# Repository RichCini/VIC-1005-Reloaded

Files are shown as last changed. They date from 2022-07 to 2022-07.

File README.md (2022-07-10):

# VIC-1005-Reloaded
The VIC-1005R is a 3-slot expansion backplane for the VIC-20 computer system.

The VIC-1005R (Reloaded) is a reimagination of the original but customized
for the various "reloaded" VIC-20s that have a vertical (Atari 2600-like)
expansion connector. It uses two boards -- the expansion connector board
and the multi-slot backplane -- connected by a 2x25 IDC ribbon cable.
It includes a reset switch and separate fuse to protect the backplane.

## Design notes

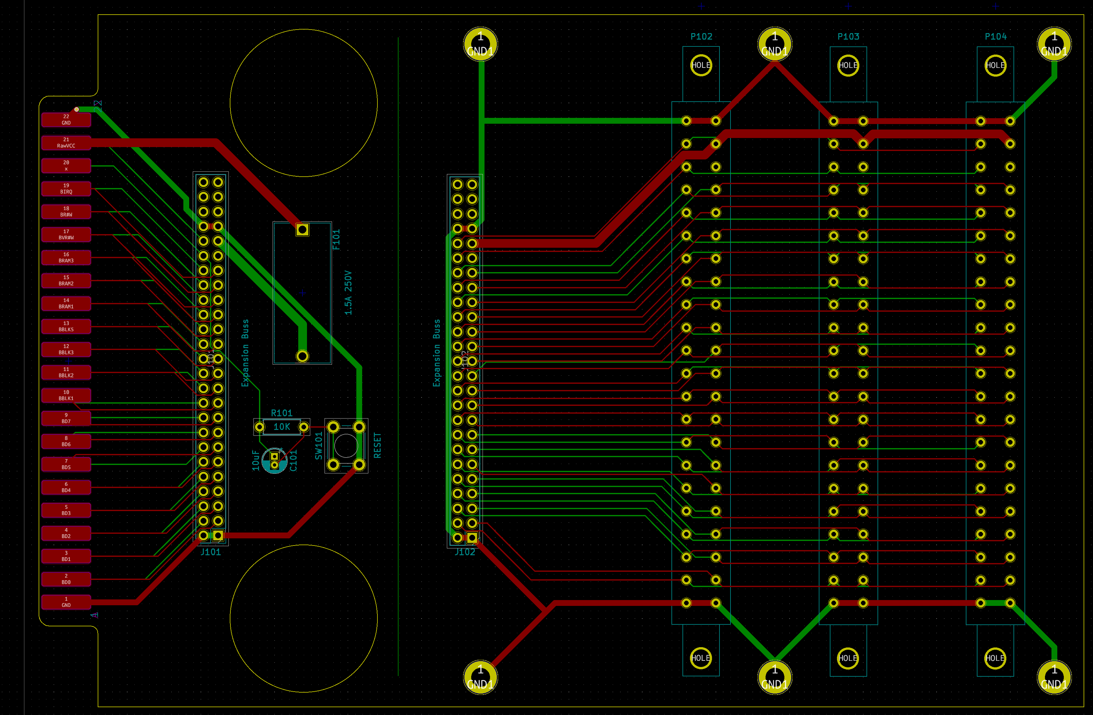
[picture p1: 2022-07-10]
Screen Shot 2022-07-10 at 12.23.37 PM.png

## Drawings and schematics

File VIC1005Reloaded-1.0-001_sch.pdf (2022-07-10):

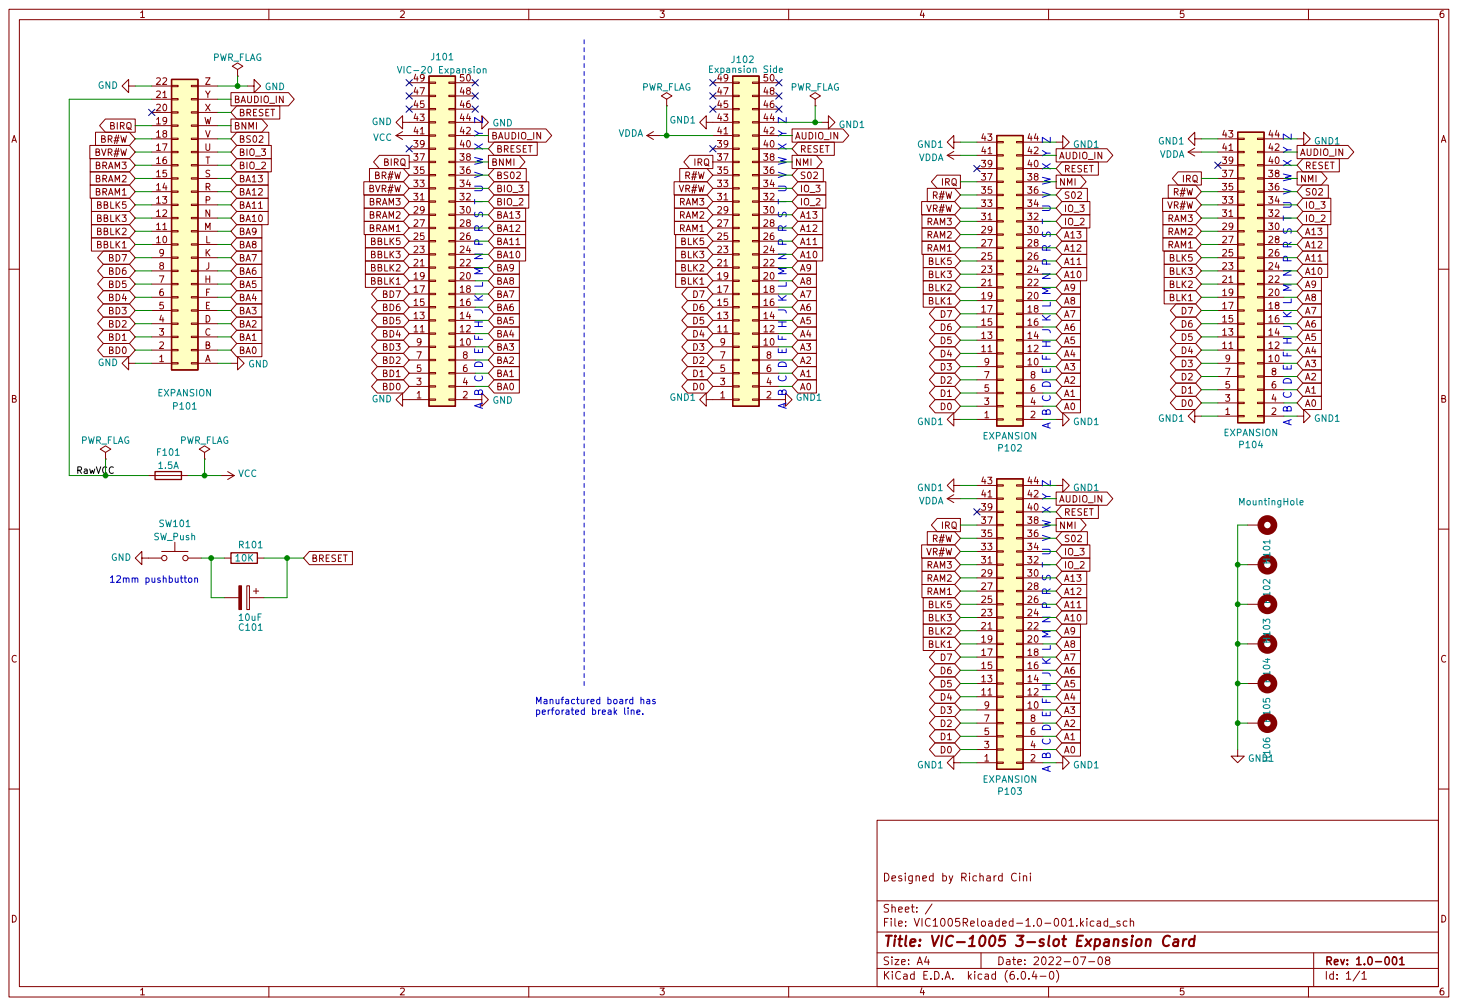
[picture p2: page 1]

Id: 1/1 Title: VIC-1005 3-slot Expansion Card

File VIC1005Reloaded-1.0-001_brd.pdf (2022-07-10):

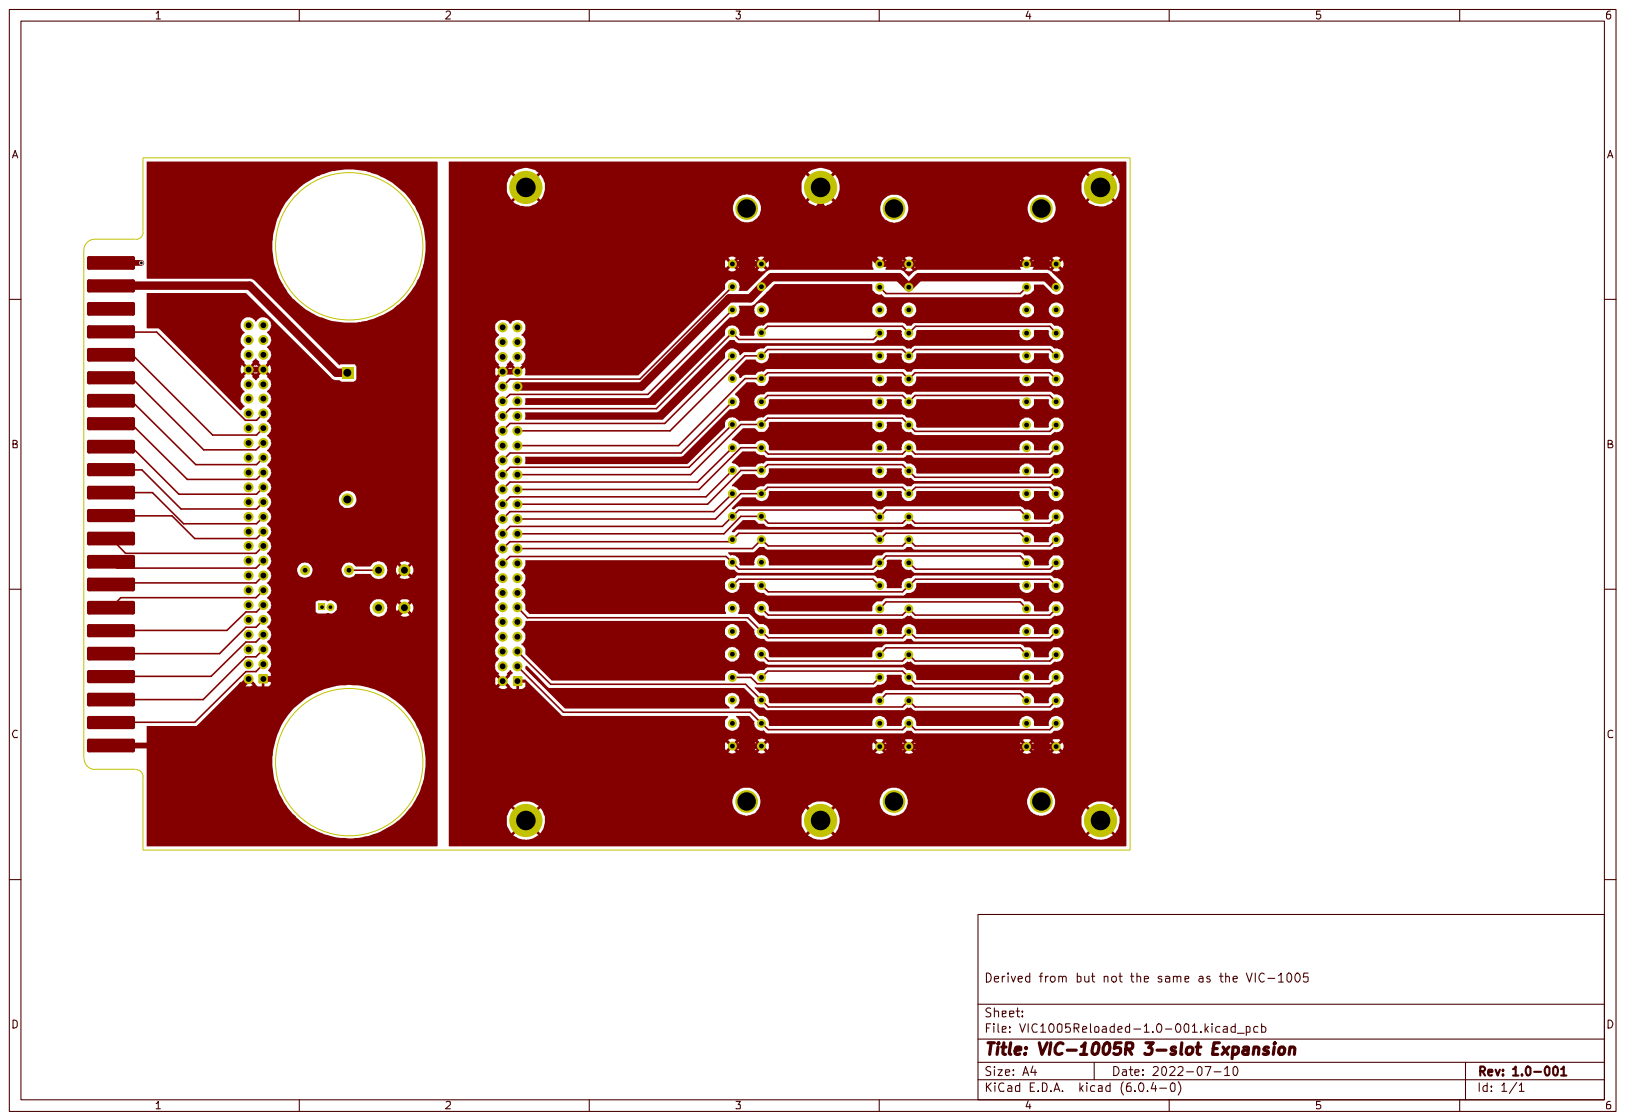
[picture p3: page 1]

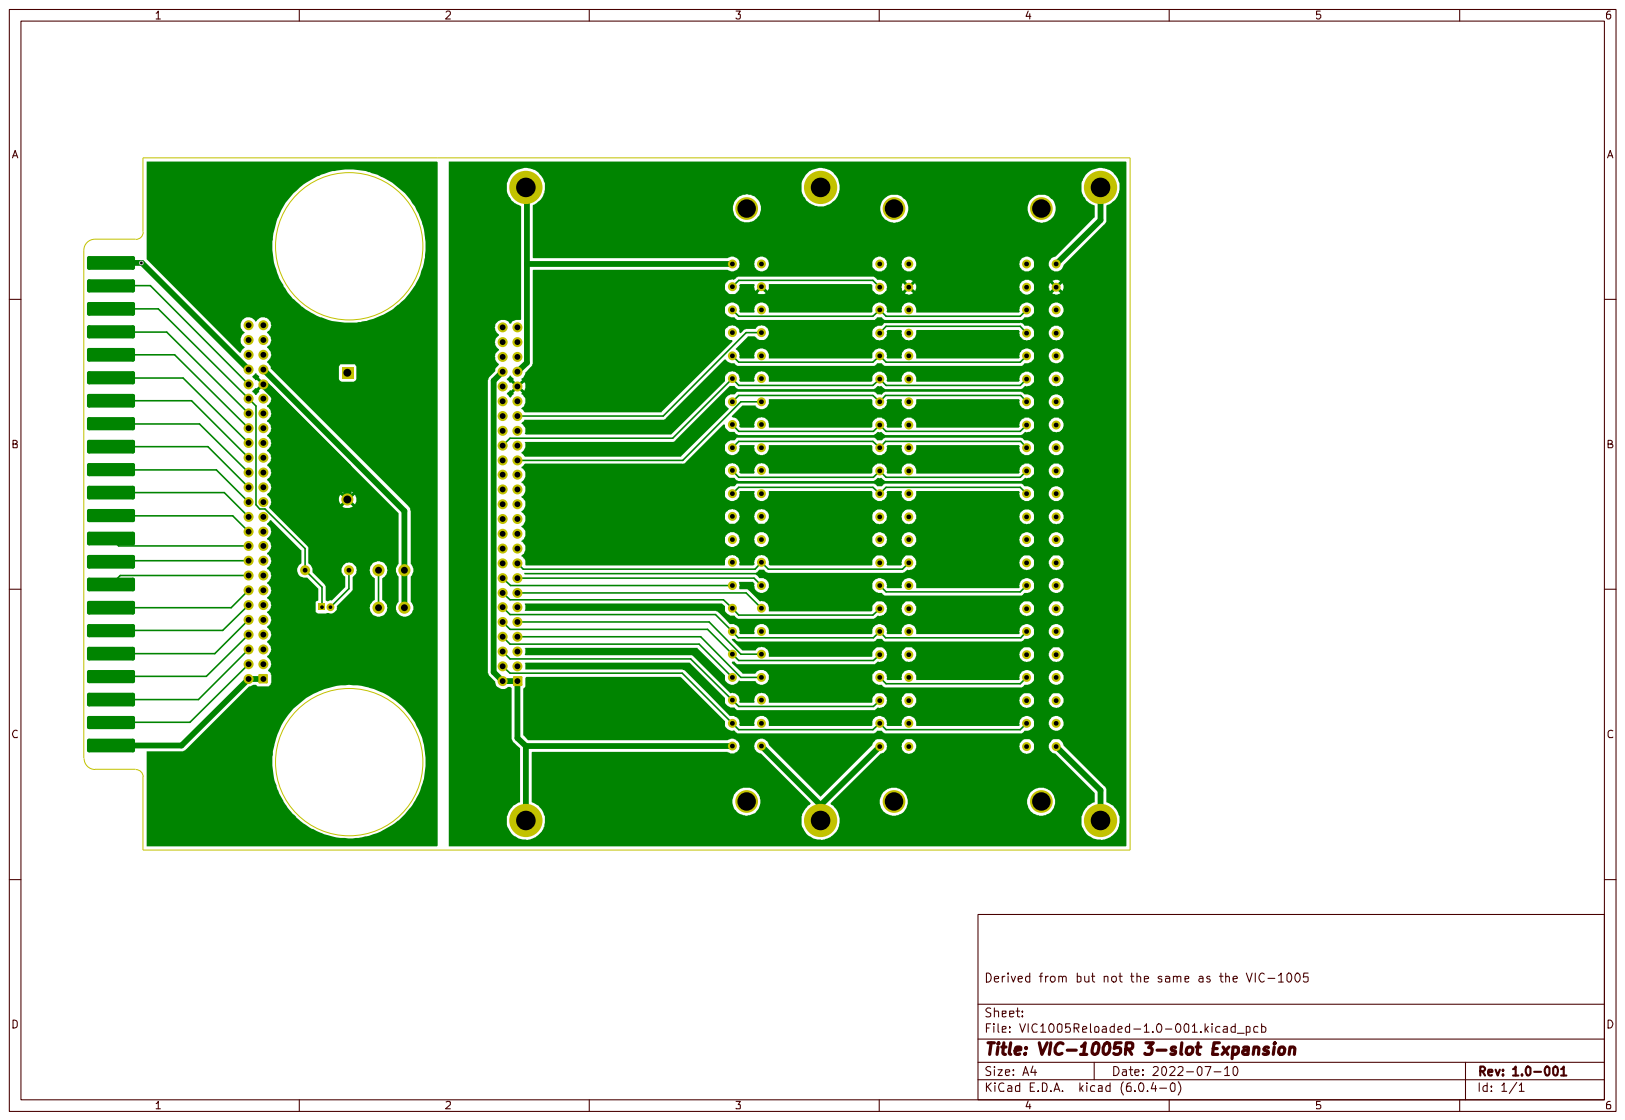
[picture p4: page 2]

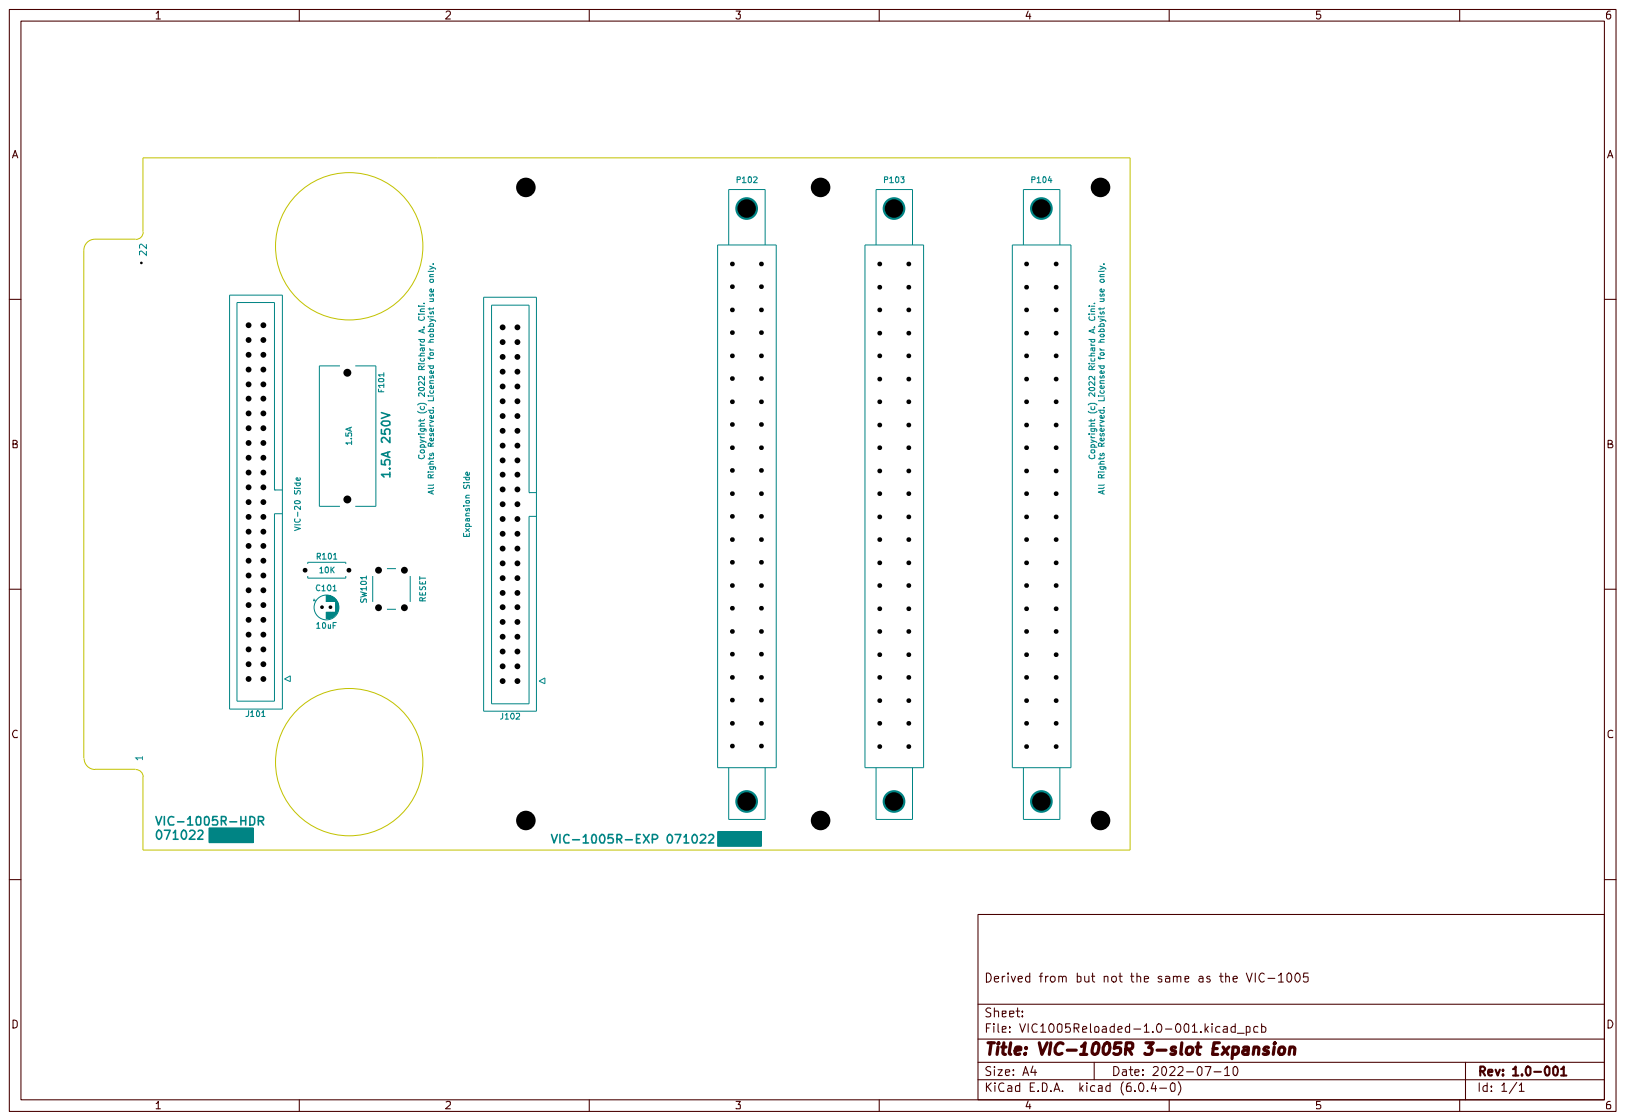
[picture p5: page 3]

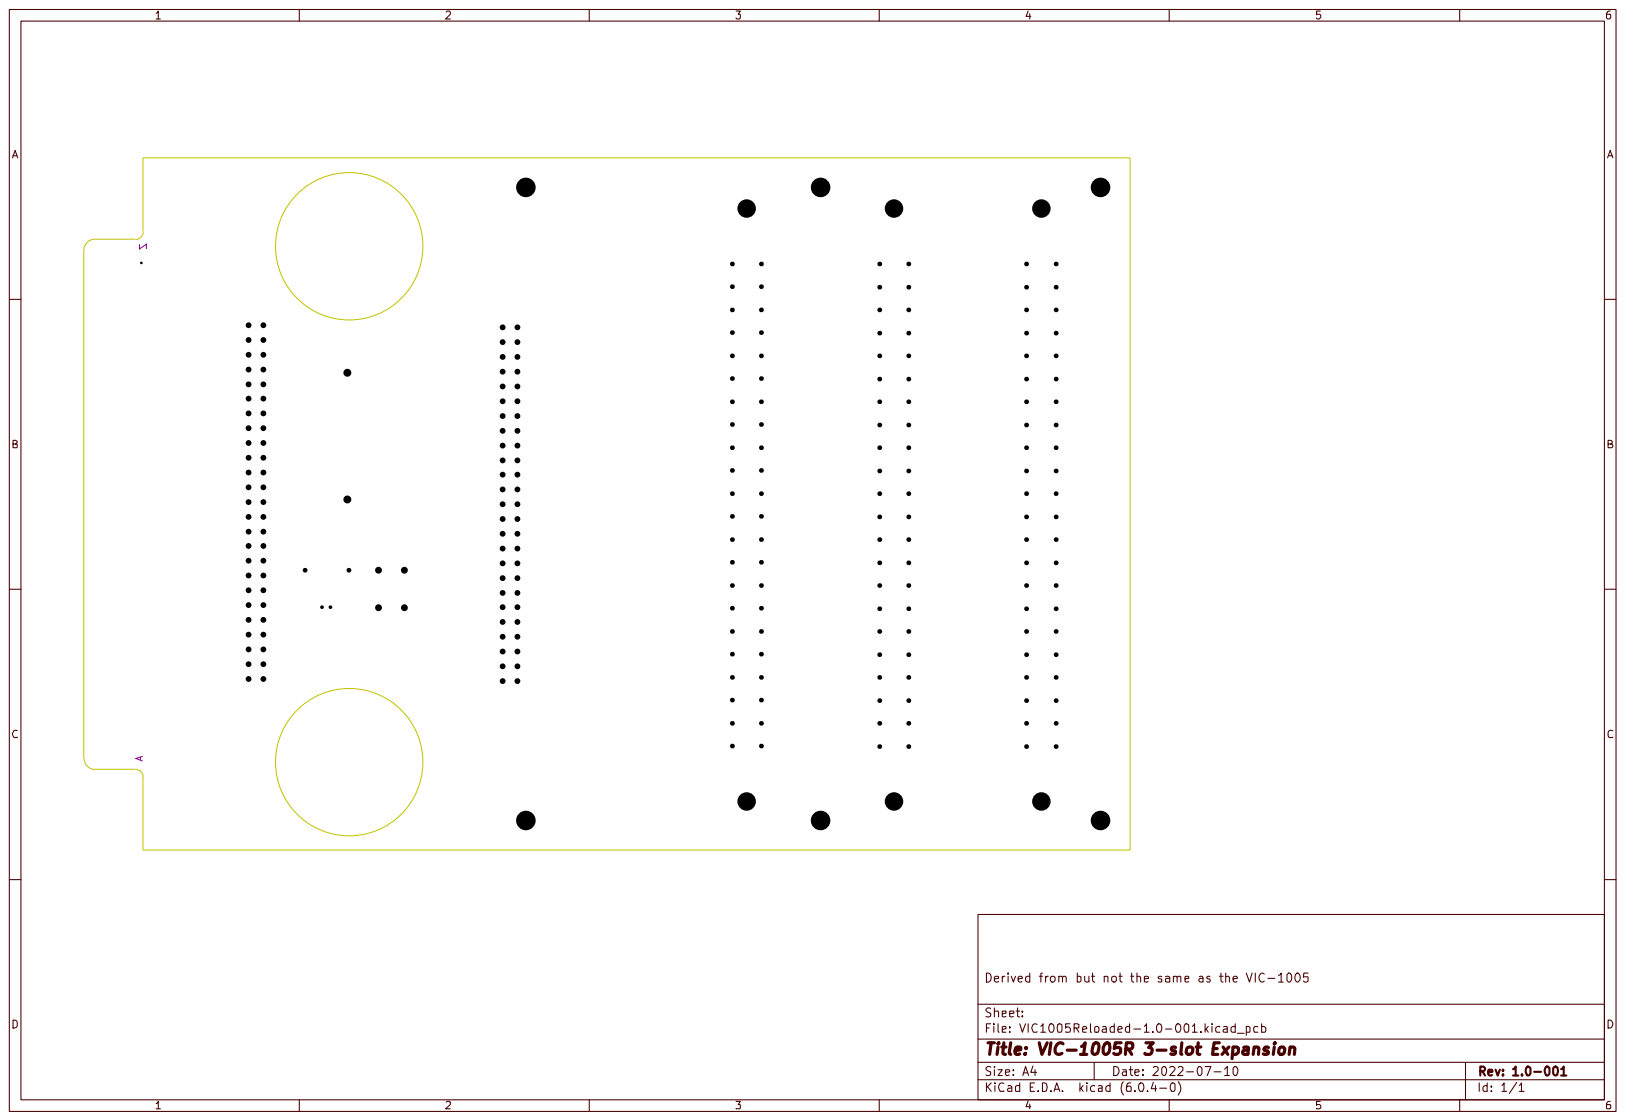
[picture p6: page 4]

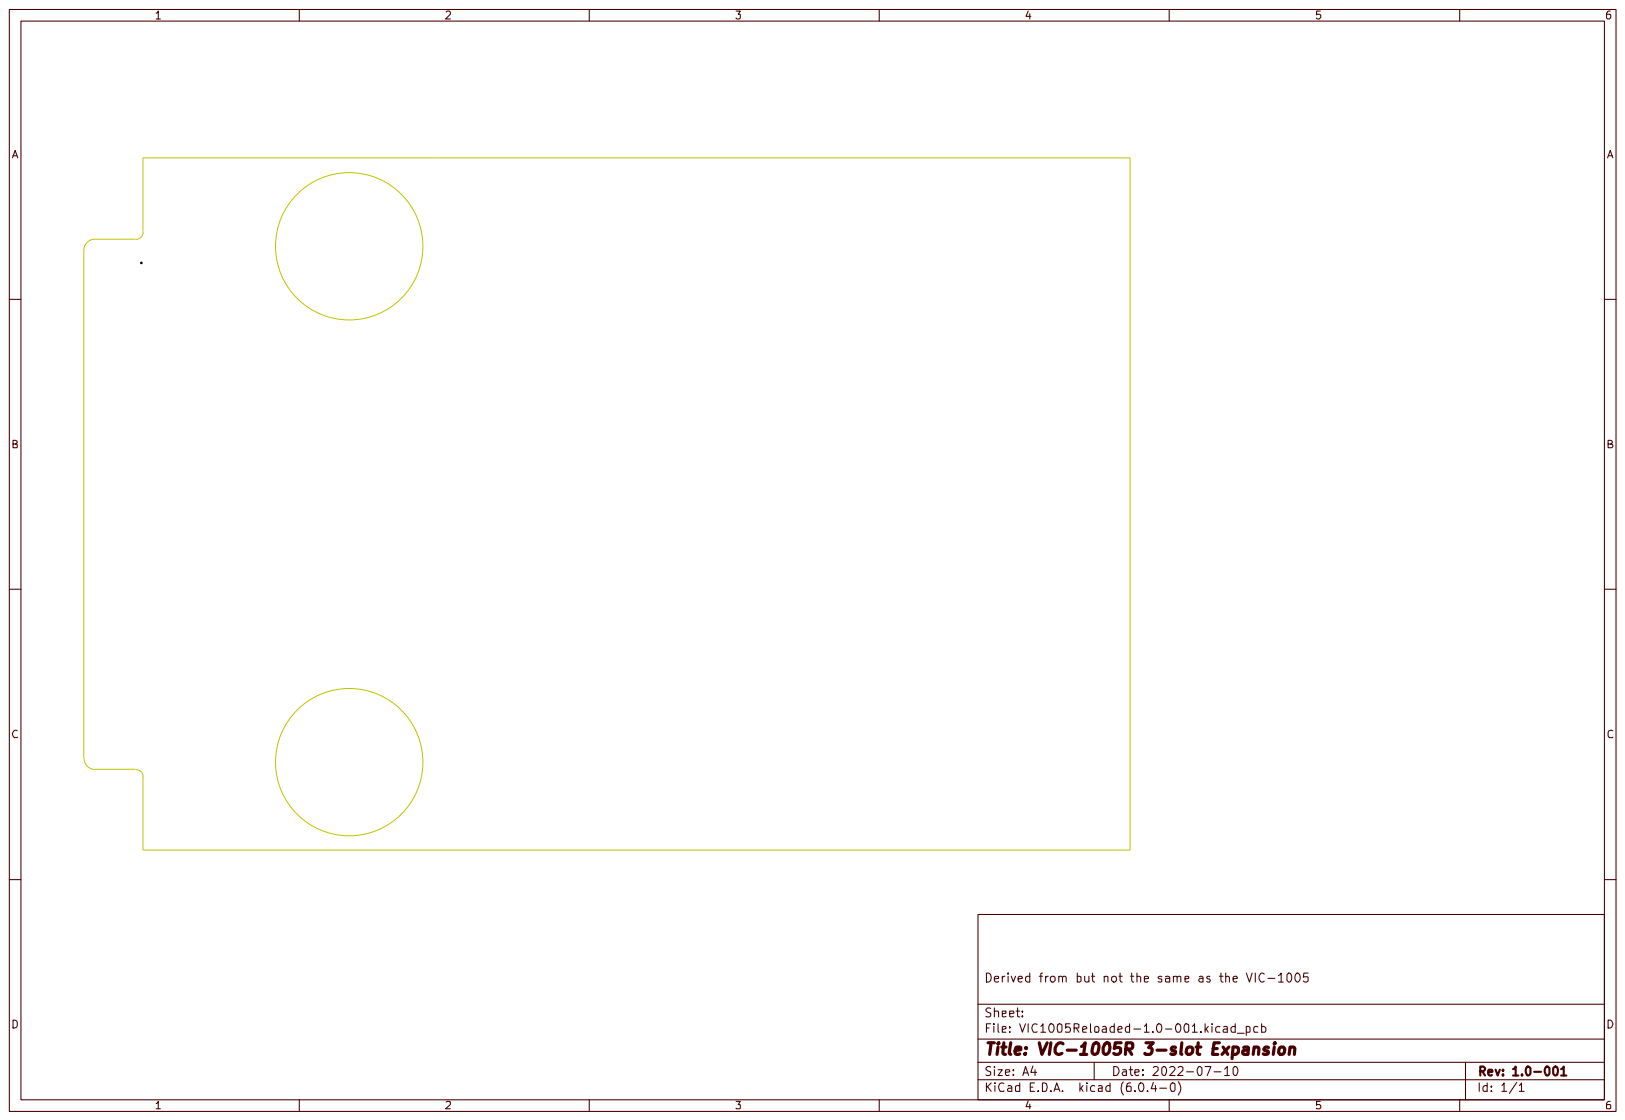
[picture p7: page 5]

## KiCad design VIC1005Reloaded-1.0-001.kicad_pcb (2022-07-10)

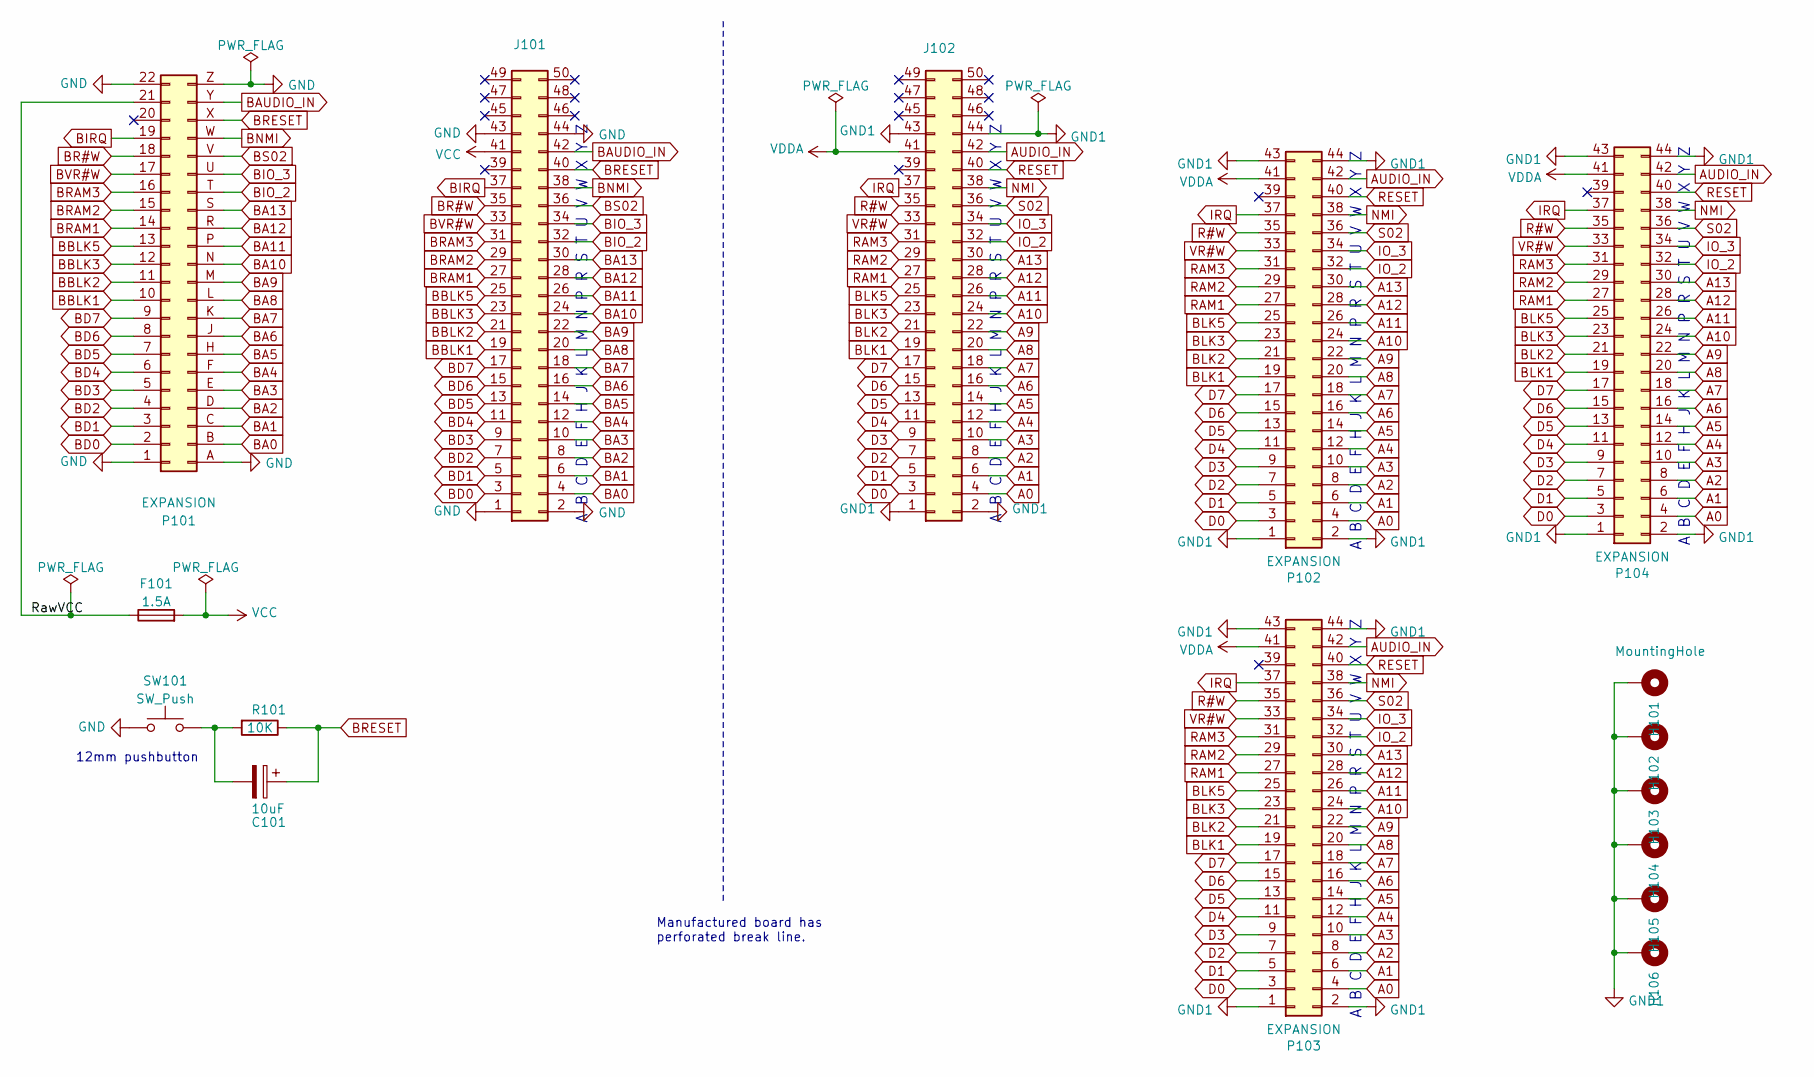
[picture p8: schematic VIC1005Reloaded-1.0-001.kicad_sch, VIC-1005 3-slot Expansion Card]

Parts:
C101: 10uF; CP_Radial_D4.0mm_P1.50mm
F101: 1.5A; FUSE_4527
H101, H102, H103, H104, H105, H106: MountingHole; MountingHole_3.2mm_M3_DIN965_Pad
J101, J102: (no value)
P101: EXPANSION; MA156-22-2
P102, P103, P104: EXPANSION; EDAC_02_22_Card_Edge_Connector
R101: 10K; R_Axial_DIN0207_L6.3mm_D2.5mm_P7.62mm_Horizontal
SW101: SW_Push; SW_PUSH_6mm

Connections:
/RawVCC: F101.1, P101.21
A0: J102.4, P102.4, P103.4, P104.4
A1: J102.6, P102.6, P103.6, P104.6
A2: J102.8, P102.8, P103.8, P104.8
A3: J102.10, P102.10, P103.10, P104.10
A4: J102.12, P102.12, P103.12, P104.12
A5: J102.14, P102.14, P103.14, P104.14
A6: J102.16, P102.16, P103.16, P104.16
A7: J102.18, P102.18, P103.18, P104.18
A8: J102.20, P102.20, P103.20, P104.20
A9: J102.22, P102.22, P103.22, P104.22
A10: J102.24, P102.24, P103.24, P104.24
A11: J102.26, P102.26, P103.26, P104.26
A12: J102.28, P102.28, P103.28, P104.28
A13: J102.30, P102.30, P103.30, P104.30
AUDIO_IN: J102.42, P102.42, P103.42, P104.42
BA0: J101.4, P101.B
BA1: J101.6, P101.C
BA2: J101.8, P101.D
BA3: J101.10, P101.E
BA4: J101.12, P101.F
BA5: J101.14, P101.H
BA6: J101.16, P101.J
BA7: J101.18, P101.K
BA8: J101.20, P101.L
BA9: J101.22, P101.M
BA10: J101.24, P101.N
BA11: J101.26, P101.P
BA12: J101.28, P101.R
BA13: J101.30, P101.S
BAUDIO_IN: J101.42, P101.Y
BBLK1: J101.19, P101.10
BBLK2: J101.21, P101.11
BBLK3: J101.23, P101.12
BBLK5: J101.25, P101.13
BD0: J101.3, P101.2
BD1: J101.5, P101.3
BD2: J101.7, P101.4
BD3: J101.9, P101.5
BD4: J101.11, P101.6
BD5: J101.13, P101.7
BD6: J101.15, P101.8
BD7: J101.17, P101.9
BIO_2: J101.32, P101.T
BIO_3: J101.34, P101.U
BIRQ: J101.37, P101.19
BLK1: J102.19, P102.19, P103.19, P104.19
BLK2: J102.21, P102.21, P103.21, P104.21
BLK3: J102.23, P102.23, P103.23, P104.23
BLK5: J102.25, P102.25, P103.25, P104.25
BNMI: J101.38, P101.W
BR#W: J101.35, P101.18
BRAM1: J101.27, P101.14
BRAM2: J101.29, P101.15
BRAM3: J101.31, P101.16
BRESET: C101.1, J101.40, P101.X, R101.1
BS02: J101.36, P101.V
BVR#W: J101.33, P101.17
D0: J102.3, P102.3, P103.3, P104.3
D1: J102.5, P102.5, P103.5, P104.5
D2: J102.7, P102.7, P103.7, P104.7
D3: J102.9, P102.9, P103.9, P104.9
D4: J102.11, P102.11, P103.11, P104.11
D5: J102.13, P102.13, P103.13, P104.13
D6: J102.15, P102.15, P103.15, P104.15
D7: J102.17, P102.17, P103.17, P104.17
GND: J101.1, J101.2, J101.43, J101.44, P101.1, P101.22, P101.A, P101.Z, SW101.1
GND1: H101.1, H102.1, H103.1, H104.1, H105.1, H106.1, J102.1, J102.2, J102.43, J102.44, P102.1, P102.2, P102.43, P102.44, P103.1, P103.2, P103.43, P103.44, P104.1, P104.2, P104.43, P104.44
IO_2: J102.32, P102.32, P103.32, P104.32
IO_3: J102.34, P102.34, P103.34, P104.34
IRQ: J102.37, P102.37, P103.37, P104.37
NMI: J102.38, P102.38, P103.38, P104.38
unnamed: C101.2, R101.2, SW101.2
R#W: J102.35, P102.35, P103.35, P104.35
RAM1: J102.27, P102.27, P103.27, P104.27
RAM2: J102.29, P102.29, P103.29, P104.29
RAM3: J102.31, P102.31, P103.31, P104.31
RESET: J102.40, P102.40, P103.40, P104.40
S02: J102.36, P102.36, P103.36, P104.36
VCC: F101.2, J101.41
VDDA: J102.41, P102.41, P103.41, P104.41
VR#W: J102.33, P102.33, P103.33, P104.33

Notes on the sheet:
A B C D E F H J K L M N P R S T U V W X Y Z
12mm pushbutton
Manufactured board has perforated break line.

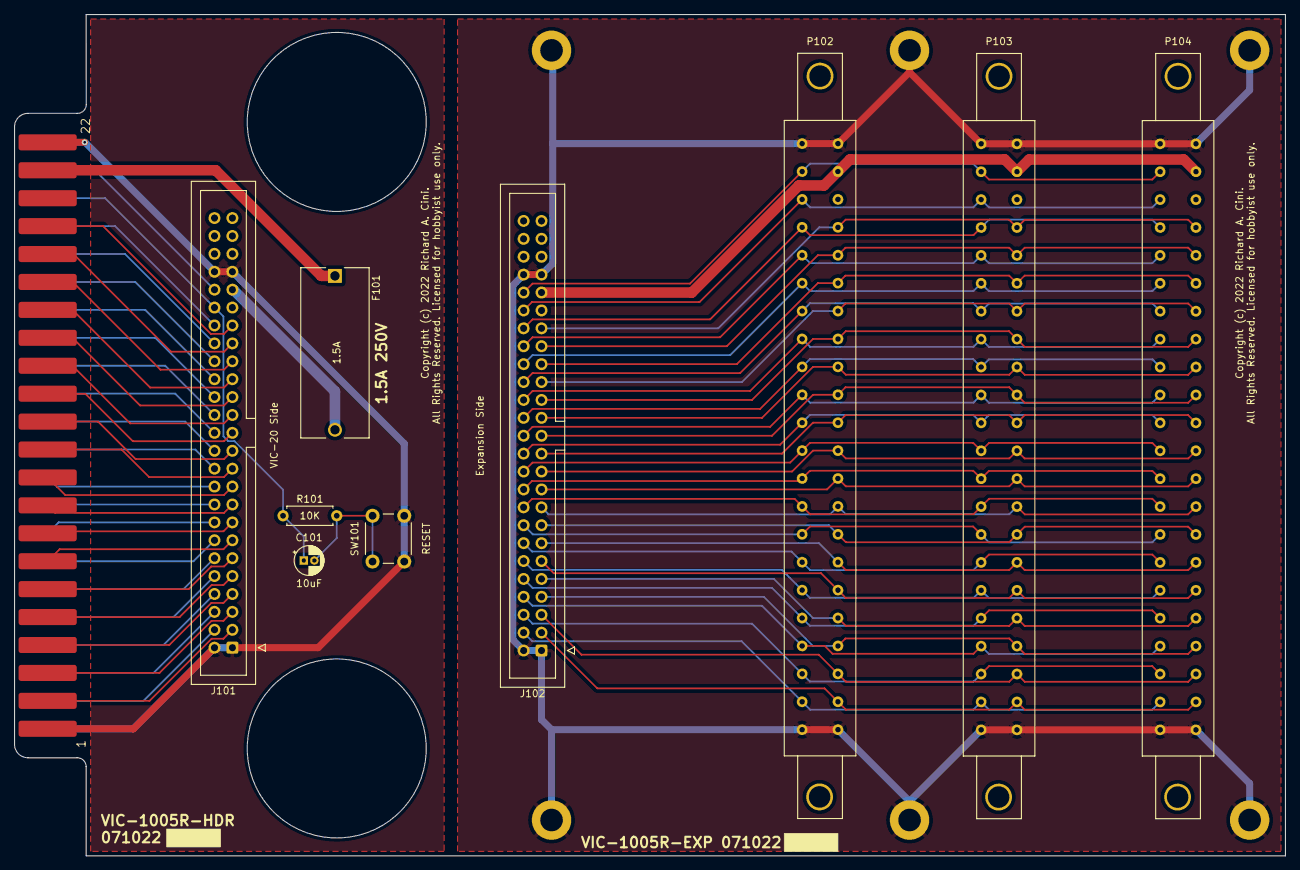
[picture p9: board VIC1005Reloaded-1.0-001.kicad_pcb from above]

Board: 2 copper layers, 180.3 x 119.4 mm, 16 parts (0 on the bottom side), 82 nets.

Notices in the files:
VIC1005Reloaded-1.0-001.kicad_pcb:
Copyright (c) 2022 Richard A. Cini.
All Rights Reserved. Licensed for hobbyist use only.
